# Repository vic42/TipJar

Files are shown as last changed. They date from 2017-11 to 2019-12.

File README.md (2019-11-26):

# TipJar
Vienna Repair Cafe talking tip jar

DESCRIPTION
===========

This is a *talking* tip jar design that is able to differentiate between coins and banknotes to utter two different spoken, sung or screamed messages accordingly.
It is a Lo-Fi approach meant to reduce cost as well as programming effort in order to get it done and ultimately keep it easily reproducible.
Feel free to use and/or comment.

# HOW IT WORKS

The board detects objects in the gap of two photointerrupters and measures the time than an object spends to pass the photointerrupters. If the time is below a certain threshold a coin is detected and one of the sound modules gets activated. if the time is above that threshold a banknote is detected and the other sound module is activated.
This way two different sound messages are played depending on the type of cash thrown into the tip jar.

# HARDWARE

The hardware is prepared for two modes of sound generation:

* sound recorded on one or two Chinese sound modules (e.g. 2 x ISD1820)
* sound generation by the microcontroller itself

Depending on which mode you prefer you can omit some of the components on the PCB

* first option: R7, D2, L2, C5, L1, C3, P2
* second option: BT1, D3, D4, R8, R10, Q3, Q6, P4, P5

There are various options powering the circuit:

* LiPo battery with micro USB power supply as charger
* 5V micro USB power supply only

Depending on if you need battery supply you can leave out some components

* with battery: U2
* without battery: U1, R1, R2, R3, JP1, P3

Warning: the PN2222A SOT23 footprint of the current PCB has base and emitter swapped.

# SOFTWARE

Currently there is a simplistic C program in the repository that switches on the optointerrupters for 1 ms every 10 ms (10% duty cycle saves power) to see if one of them is interrupted by an object. if so, it counts the cycles while the object occludes the detector. If 8 cycles have passed before the detector sees light again a banknote is assumed to have passed the detector. Oterwise the object detected is assumed to have been a coin.

# BUILD

There is a Makefile included with the code. It needs to be adjusted to your AVR-ISP interface in order to upload the code to the microcontroller directly.

# SEE ALSO

* https://repaircafe.wien/

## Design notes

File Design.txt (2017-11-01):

Batteriebetrieb
Audio-Ausgang (Samples abspielen)
LED Blinken
Gabellichtschranke für Geld
Schaltausgänge
Lipo/Charger

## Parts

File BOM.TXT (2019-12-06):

TipJar Project BOM
==================

PCB                  5.00 €
ATTINY85             1.50 €
MIC5504              0.15 €
MCP73831             0.50 €
TSM2301 (2 pcs)      1.00 €
TSM2302              0.30 €
MMBT2222 (6 pcs)     0.60 €
ON1120 (2pcs)        3.00 €
PMEG6030 (3 pcs)     1.50 €
CR2032 Holder        0.50 €
Sound ISD1820 (2x)   4.00 €
Inductors (2 pcs)    2.00 €
Lipo Battery         3.50 €
Other Parts          5.00 €
---------------------------
SUM                 28.05 €

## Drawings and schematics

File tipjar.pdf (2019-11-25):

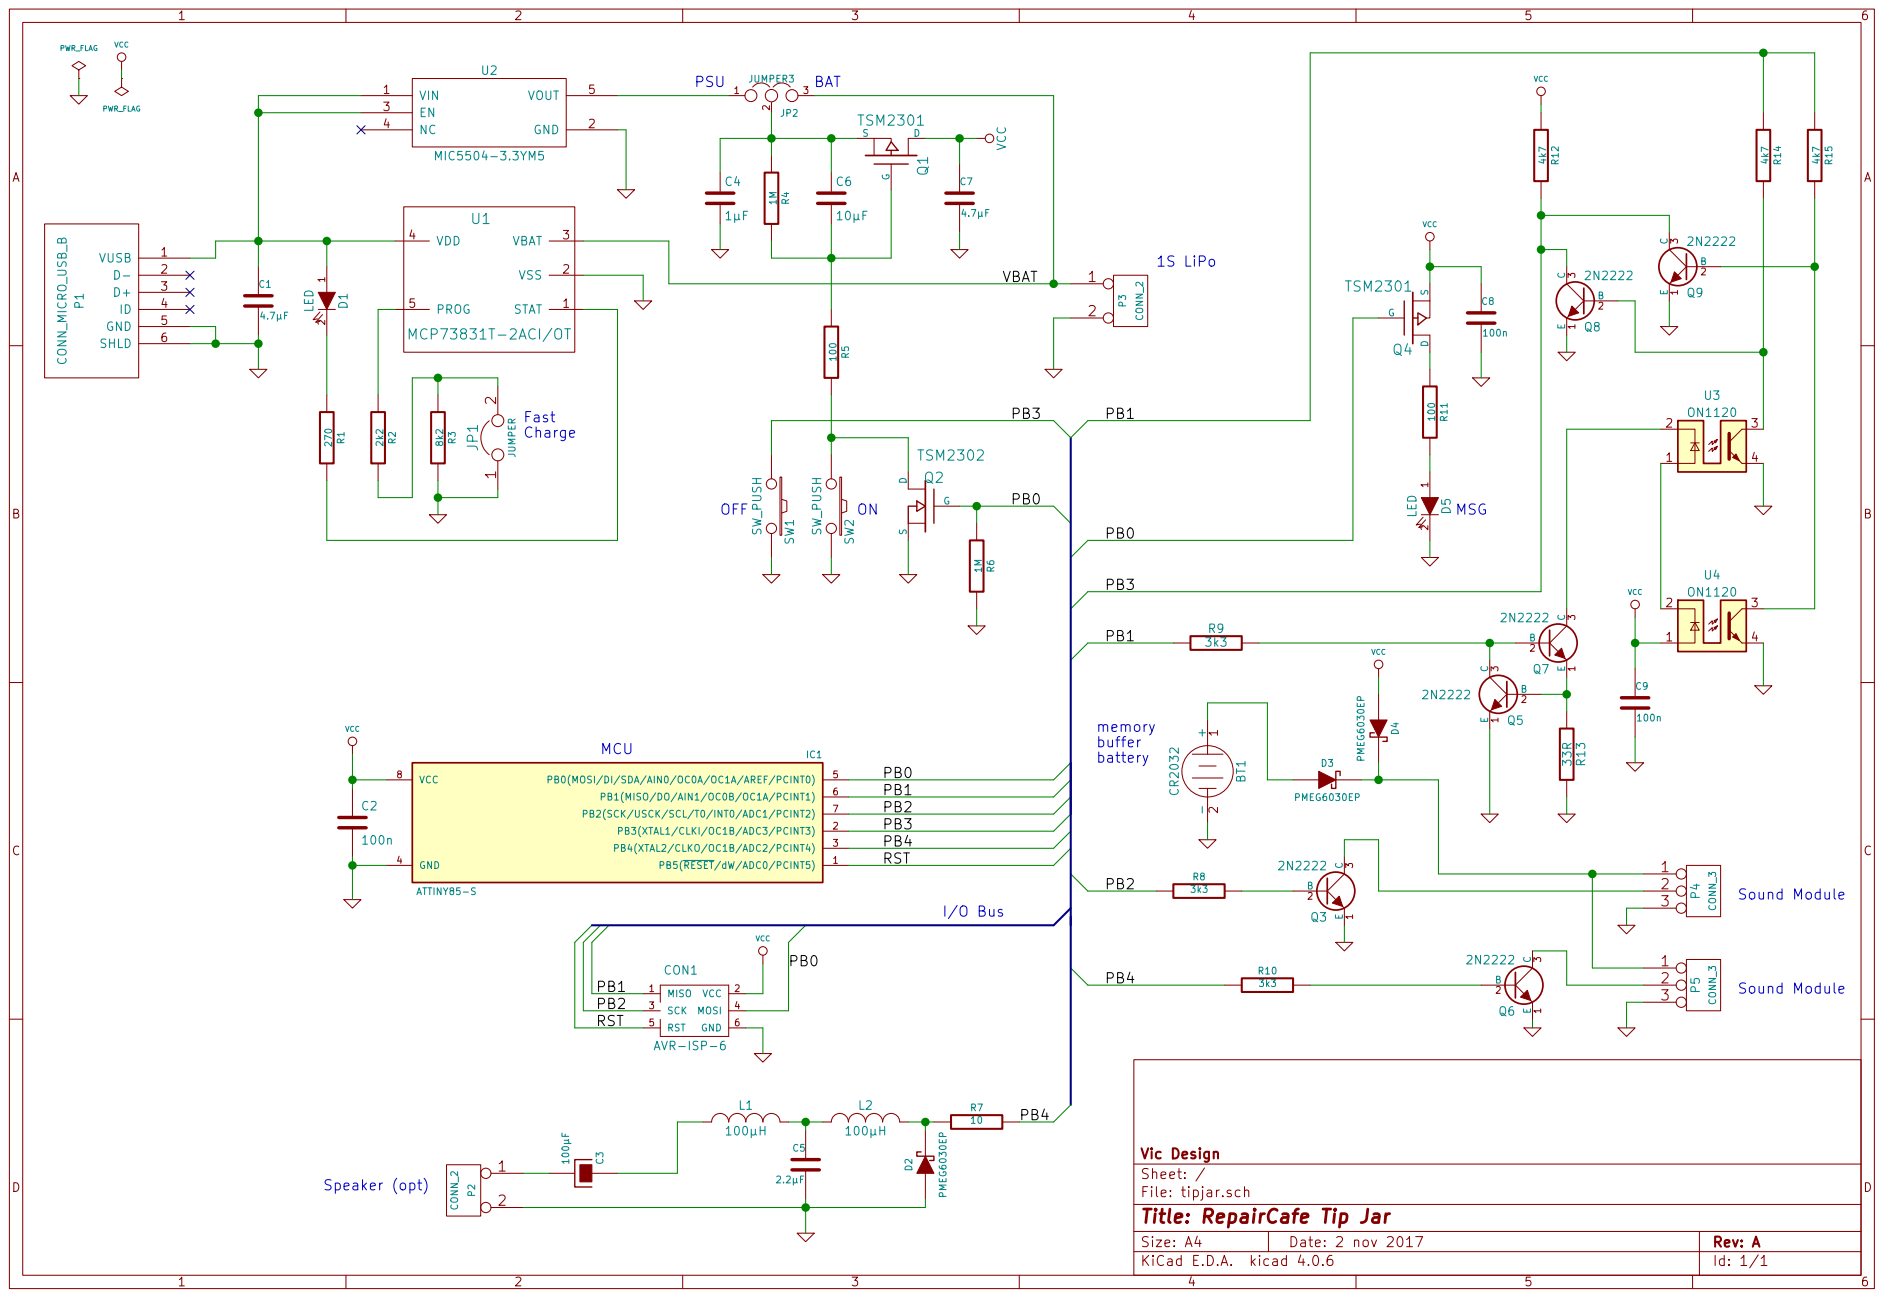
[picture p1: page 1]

-2 BT1 CR2032 D3 PMEG6030EP memory buffer battery PB4 VCC D2 PMEG6030EP C4

File: tipjar.sch Sheet: / Vic Design

Id: 1/1 Title: RepairCafe Tip Jar

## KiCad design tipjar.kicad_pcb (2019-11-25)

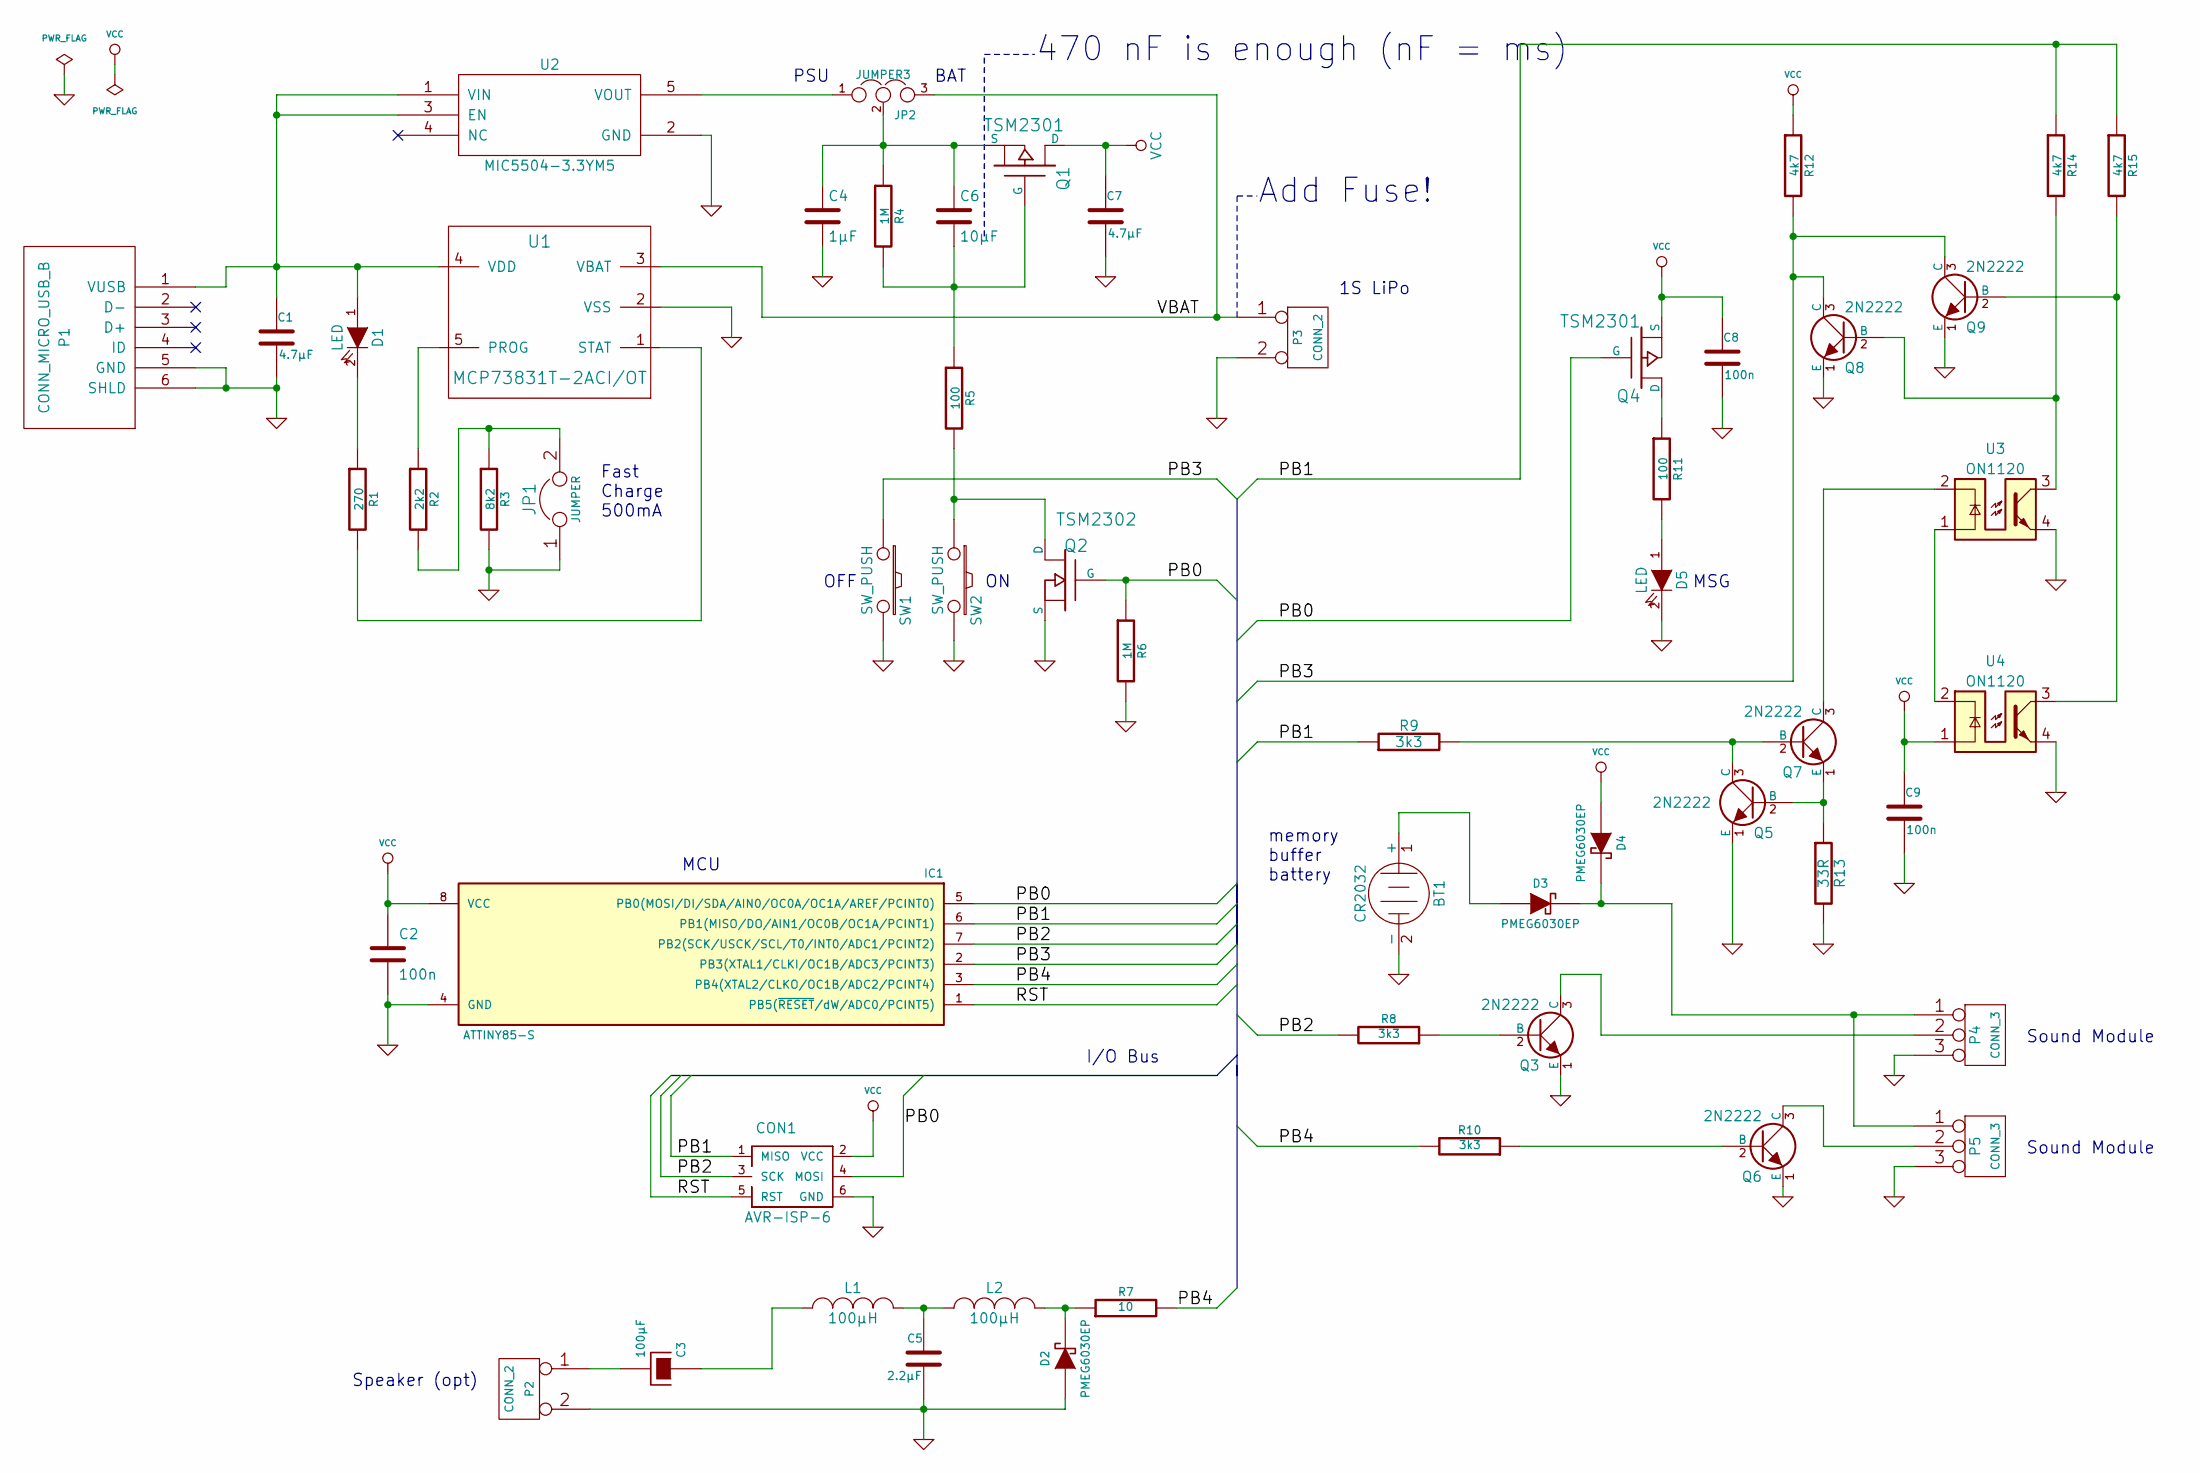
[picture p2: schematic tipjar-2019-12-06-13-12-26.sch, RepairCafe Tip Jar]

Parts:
BT1: CR2032; Keystone_3034_1x20mm-CoinCell
C1, C7: 4.7µF; C_0805
C2, C8, C9: 100n; C_0603
C3: 100µF; CP_Elec_6.3x7.7
C4: 1µF; C_0805
C5: 2.2µF; C_0805
C6: 10µF; C_0805
CON1: AVR-ISP-6; Pin_Header_Straight_2x03_Pitch2.54mm
D1, D5: LED; LED_0603
D2, D3, D4: PMEG6030EP; SOD-128
IC1: ATTINY85-S; SOIC127P798X216-8N
JP1: JUMPER; Pin_Header_Straight_1x02_Pitch2.54mm
JP2: JUMPER3; Pin_Header_Straight_1x03_Pitch2.54mm
L1, L2: 100µH; L_12x12mm_h8mm
P1: CONN_MICRO_USB_B; MICRO-B_USB
P2: CONN_2; Pin_Header_Straight_1x02_Pitch2.54mm
P3: CONN_2; JST_XH_B02B-XH-A_02x2.50mm_Straight
P4, P5: CONN_3; Pin_Header_Straight_1x03_Pitch2.54mm
Q1, Q4: TSM2301; SOT-23
Q2: TSM2302; SOT-23
Q3, Q5, Q6, Q7, Q8, Q9: 2N2222; SOT-23
R1: 270; R_0603
R2: 2k2; R_0603
R3: 8k2; R_0603
R4, R6: 1M; R_0603
R5, R11: 100; R_0603
R7: 10; R_0805_HandSoldering
R8, R9, R10: 3k3; R_0603
R12, R14, R15: 4k7; R_0603
R13: 33R; R_0603
SW1, SW2: SW_PUSH; SW_SPST_EVQPE1
U1: MCP73831T-2ACI/OT; SOT-23-5
U2: MIC5504-3.3YM5; SOT-23-5
U3, U4: ON1120

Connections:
/PB0: CON1.4 (MOSI), IC1.5 (PB0(MOSI/DI/SDA/AIN0/OC0A/OC1A/AREF/PCI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), Q2.1 (G), Q4.1 (G), R6.1
/PB1: CON1.1 (MISO), IC1.6 (PB1(MISO/DO/AIN1/OC0B/OC1A/PCINT1)), R9.1, R14.1, R15.1
/PB2: CON1.3 (SCK), IC1.7 (PB2(SCK/USCK/SCL/T0/INT0/ADC1/PCINT2)), R8.2
/PB3: IC1.2 (PB3(XTAL1/CLKI/OC1B/ADC3/PCINT3)), Q8.3 (C), Q9.3 (C), R12.2, SW1.1
/PB4: IC1.3 (PB4(XTAL2/CLKO/OC1B/ADC2/PCINT4)), R7.2, R10.2
/RST: CON1.5 (RST), IC1.1 (PB5(~RESET~/dW/ADC0/PCINT5))
/VBAT: JP2.3, P3.1, U1.3 (VBAT)
GND: BT1.2 (-), C1.2, C2.2, C4.2, C5.2, C7.2, C8.2, C9.2, CON1.6 (GND), D2.1 (A), D5.2 (K), IC1.4 (GND), JP1.1, P1.5 (GND), P1.6 (SHLD), P2.2 (PM), P3.2 (PM), P4.3, P5.3, Q2.2 (S), Q3.1 (E), Q5.1 (E), Q6.1 (E), Q8.1 (E), Q9.1 (E), R3.2, R6.2, R13.2, SW1.2, SW2.2, U1.2 (VSS), U2.2 (GND), U3.4, U4.4
unnamed: BT1.1 (+), D3.1 (A)
unnamed: C1.1, D1.1 (A), P1.1 (VUSB), U1.4 (VDD), U2.1 (VIN), U2.3 (EN)
unnamed: C3.1, L1.2
unnamed: C3.2, P2.1
unnamed: C4.1, C6.1, JP2.2, Q1.2 (S), R4.1
unnamed: C5.1, L1.1, L2.2
unnamed: C6.2, Q1.1 (G), R4.2, R5.1
unnamed: D1.2 (K), R1.1
unnamed: D2.2 (K), L2.1, R7.1
unnamed: D3.2 (K), D4.2 (K), P4.1, P5.1
unnamed: D5.1 (A), R11.2
unnamed: JP1.2, R2.2, R3.1
unnamed: JP2.1, U2.5 (VOUT)
unnamed: P4.2 (PM), Q3.3 (C)
unnamed: P5.2 (PM), Q6.3 (C)
unnamed: Q2.3 (D), R5.2, SW2.1
unnamed: Q3.2 (B), R8.1
unnamed: Q4.3 (D), R11.1
unnamed: Q5.2 (B), Q7.1 (E), R13.1
unnamed: Q5.3 (C), Q7.2 (B), R9.2
unnamed: Q6.2 (B), R10.1
unnamed: Q7.3 (C), U3.2
unnamed: Q8.2 (B), R14.2, U3.3
unnamed: Q9.2 (B), R15.2, U4.3
unnamed: R1.2, U1.1 (STAT)
unnamed: R2.1, U1.5 (PROG)
unnamed: U3.1, U4.2
VCC: C2.1, C7.1, C8.1, C9.1, CON1.2 (VCC), D4.1 (A), IC1.8 (VCC), Q1.3 (D), Q4.2 (S), R12.1, U4.1

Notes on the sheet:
1S LiPo
Sound Module
BAT
PSU
MCU
OFF
MSG
Fast Charge 500mA
I/O Bus
Speaker (opt)
memory buffer battery
470 nF is enough (nF = ms)
Add Fuse!

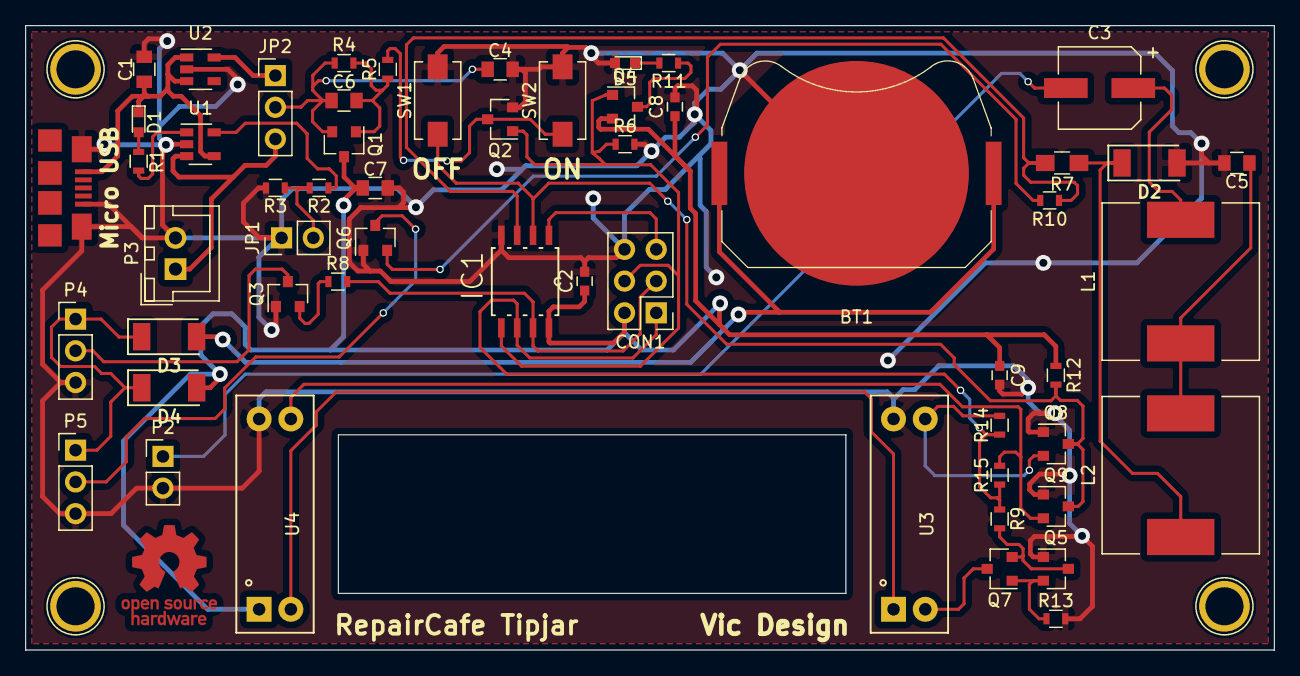
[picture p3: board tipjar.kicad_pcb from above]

Board: 2 copper layers, 100.0 x 50.0 mm, 56 parts (0 on the bottom side), 36 nets.

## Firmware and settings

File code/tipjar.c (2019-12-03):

/* The RepairCafe TipJar, Copyright (c)2017-2019 Peter Franck
 * 
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
 * This program is distributed in the hope that it will be useful,
 * but WITHOUT ANY WARRANTY; without even the implied warranty of
 * MERCHANTABILITY or FITNESS FOR A PARTICULAR PURPOSE.  See the
 * GNU General Public License for more details.
 * You should have received a copy of the GNU General Public License
 * along with this program.  If not, see <http://www.gnu.org/licenses/>.
 */

#define F_CPU	8000000UL
#include <avr/io.h>
#include <util/delay.h>
#include <avr/interrupt.h>

#define set(x) |= (1<<x)
#define clr(x) &=~(1<<x)
#define inv(x) ^=(1<<x)

/* port B pin definitions */
#define SND1	PB2		// sound module 1 trigger pin
#define SND2	PB4		// sound module 2 trigger pin
#define SNDOUT	PB4		// sound waveform output pin
#define PWRLED	PB0		// HIGH=hold power, LOW=light message LED
#define PHOTR	PB3		// photo transistor input
#define PWROFF	PB3		// power off switch input (muxed)
#define IRLED	PB1		// HIGH=IR LEDs on

void init(void);

int is_interrupted(void)	// return 1 if photointerrupter dark
{
	int pintr;
	
	PORTB set(IRLED);		// switch on IR LEDs
	_delay_ms(1);			// wait for IR to settle
	pintr = !(PINB & (1<<PHOTR));	// read the photo interrupter
	PORTB clr(IRLED);		// switch off IR LEDs (save power)
	return pintr;
}

int vcc_low(void)			// return 0 if VCC OK, != 0 if VCC low
{
	volatile long result;
	
	ADCSRA |= _BV(ADSC);			// Start conversion
	loop_until_bit_is_set(ADCSRA,ADSC);	// measuring
	result = ADC;
	result = 1126400L / result;		// Calculate Vcc (in mV); 1126400 = 1.1*1024*1000
	return (result < 3100L);		// Vcc < 3.1V
}

void main(void) {
	int sound=0;
	
	init();

	for(;;) {				// endless loop
		PORTB set(PWRLED);		// hold power, LED off
		_delay_ms(8);			// defines the PWM off-time for the power LED
		PORTB clr(PWRLED);
		_delay_ms(1);			// defines the PWM on-time for the power LED

		/* power off if switch pressed or low voltage */
		if ( !(PINB & (1<<PWROFF)) || vcc_low() ) {	// read the off switch and VCC
			PORTB set(IRLED);
			PORTB clr(PWRLED);	// switch power hold off (LED on)
			for(;;);		// halt
		}

		/* read photo interrupters */
		if (is_interrupted()) {
			++sound;
			if ( sound >= 8 ) 	{	// long sample
				sound=0;
				PORTB set(PWRLED);	// hold power, LED off
				PORTB set(SND1);
				_delay_ms(1);
				PORTB clr(SND1);
				_delay_ms(1000);
			}
		}
		else if (sound) {		// short sample
			sound=0;
			PORTB set(PWRLED);	// hold power, LED off
			PORTB set(SND2);
			_delay_ms(1);
			PORTB clr(SND2);
			_delay_ms(1000);
		}
	}
}

void init(void) {
	// set the direction of the ports
	DDRB set(PWRLED);	// PWR/LED OUTPUT
	DDRB set(SND1);		// sound module 1 OUTPUT
	DDRB set(SND2);		// sound module 2 OUTPUT
	DDRB set(IRLED);	// infrared sensor LEDs OUTPUT
	DDRB clr(PHOTR);	// phototransistor INPUT
	PORTB set(PHOTR);	// enable pullup resistor

	CLKPR = (1 << CLKPCE);	// enable clock prescaler update
	CLKPR = 0;		// set clock to maximum (= crystal/RC oscillator)
	
	PORTB clr(PWRLED);	// LED=on
	_delay_ms(700);		// avoid self-switch-on
	PORTB set(PWRLED);	// self-hold power switch (LED=off)
	PORTB set(SND1);	// set sound module inputs to LOW
	PORTB set(SND2);
	
	ADCSRA = _BV(ADEN);			// enable ADC
	ADMUX = _BV(MUX3) | _BV(MUX2);		// set ADC reference to Vcc and input internal 1.1V reference
	_delay_ms(1);				// wait for reference to settle
	ADCSRA |= _BV(ADSC);			// Start dummy ADC conversion
	loop_until_bit_is_set(ADCSRA,ADSC);	// measuring
}

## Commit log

2017-11-01 initial upload of very first attempt
    [tipjar.sch]
2017-11-01 Add lithium battery for data retention
    [tipjar.sch]
2019-11-25 First remote commit
    [tipjar.kicad_pcb, tipjar.sch]
2019-12-03 timing stuff
    [tipjar-2019-11-29-14-07-48.sch]
2019-12-06 minor updates
    [tipjar-2019-12-06-13-12-26.sch]

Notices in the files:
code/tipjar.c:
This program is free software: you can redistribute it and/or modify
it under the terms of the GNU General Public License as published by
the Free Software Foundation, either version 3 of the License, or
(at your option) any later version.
